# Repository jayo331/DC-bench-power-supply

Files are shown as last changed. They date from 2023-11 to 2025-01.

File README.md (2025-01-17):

# Multichannel linear bench power supply

Work in progress. At the start, i planned to add a switching pre-regulator and constant current control to an all-in-one linear regulator like lm350,lm317... The advantage of this solution is that since this regulator already comes with good line/load regulation i don't have to deal with extra stabilization. The problem is that those types of regulators also come with some big limits, some can not output voltages around zero, others can not handle the high current, and others are just too expensive for what they give, in general for all of the integrated solution voltage control (using DAC and MCU) is not as simple as i initially thought. Some regulators like 317 can be tweaked to output ~0V however the output is still limited to 1.5A in the case of the 317. I want to maintain the initial goals as much as possible (~0-25V, 5A per channel, simple) however commercial integrated linear regulators will not work without modifications. At this point, the only alternatives that come to mind are: 1) Tweak cheap regulators to reach voltages below 1.25V and boost the output current by adding an external pass transistor. 2) Build discretely a linear regulator that can handle these specs. For both solutions, extensive spice simulations are required to see which one performs better in dynamic load, transient, etc., and which one offers more performance at a price.

The regulators that i considered so far (without mod):

| | LM317 | LM350 | MIC29752 | LT3080 | LT3083 |
| --- | --- | --- | --- | --- | --- |
| 0V Capable | &cross; | &cross; | &cross; | &check; | &check; |
| 25V | &check; | &check; | &check; | &check; | &cross; |
| >/=5A | &cross; | &cross; | &check; | &cross; | &cross; |
| Active/In stock | &check; | &check; | &check; | &check; | &check; |
| Cheap? |Very inexpensive| Affordable | Very expensive| Affordable | Expensive |
| Easy to mod? | Easy | Easy | Difficult | Very easy | Easy |

After some simulations, i ended up considering the discrete linear topology, which shows good results even in dynamic load. The main advantages of this solution are price and flexibility, also a good side effect is that since no mysterious pre-made ic are involved it should be easy to tweak in case of future updates.

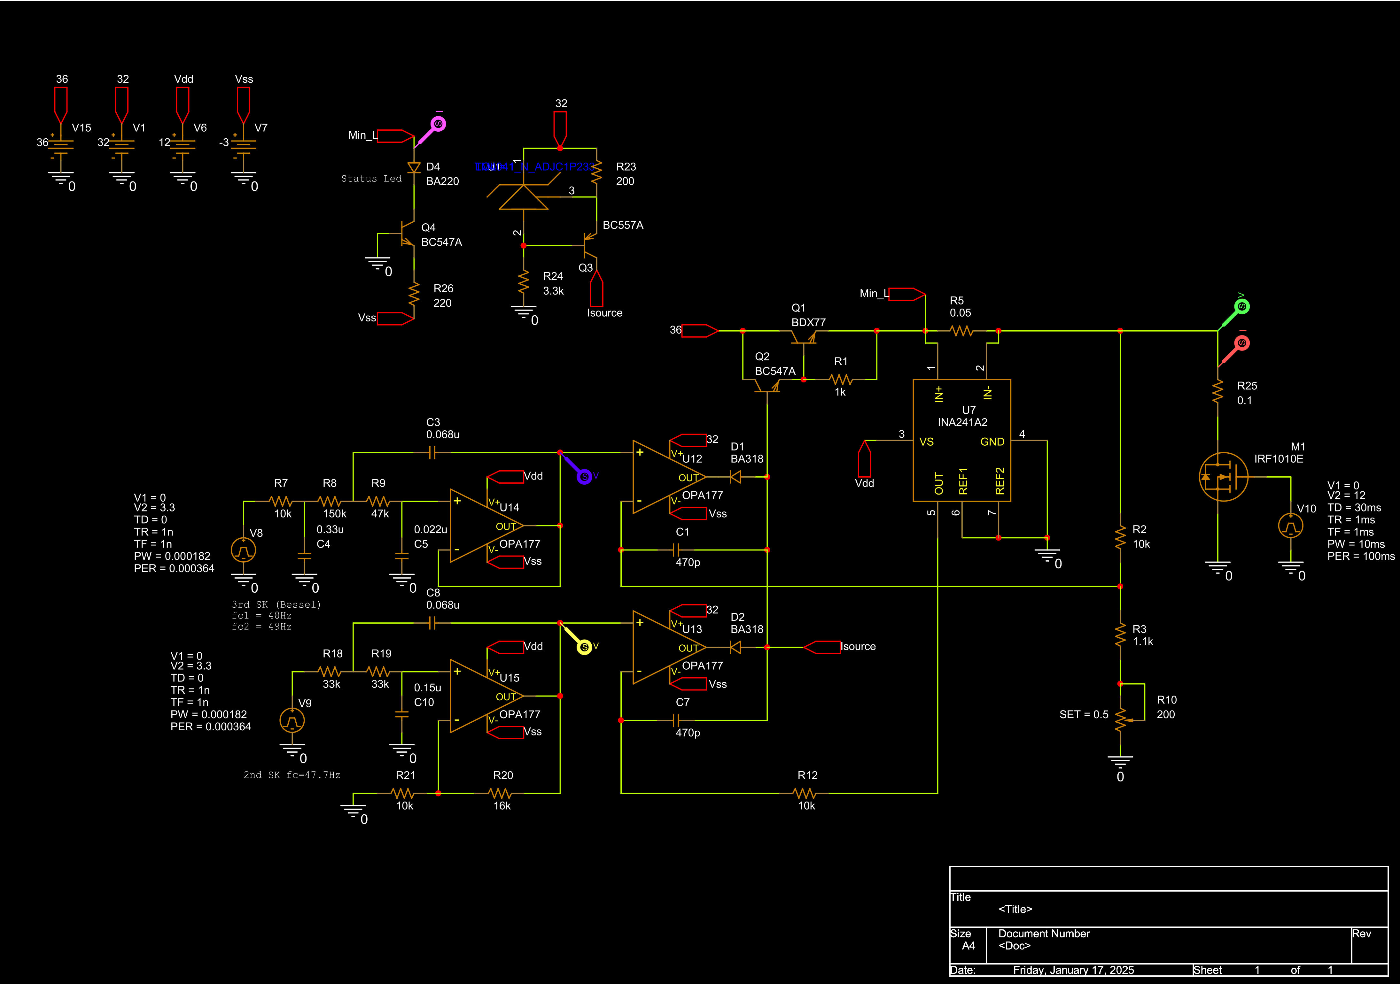
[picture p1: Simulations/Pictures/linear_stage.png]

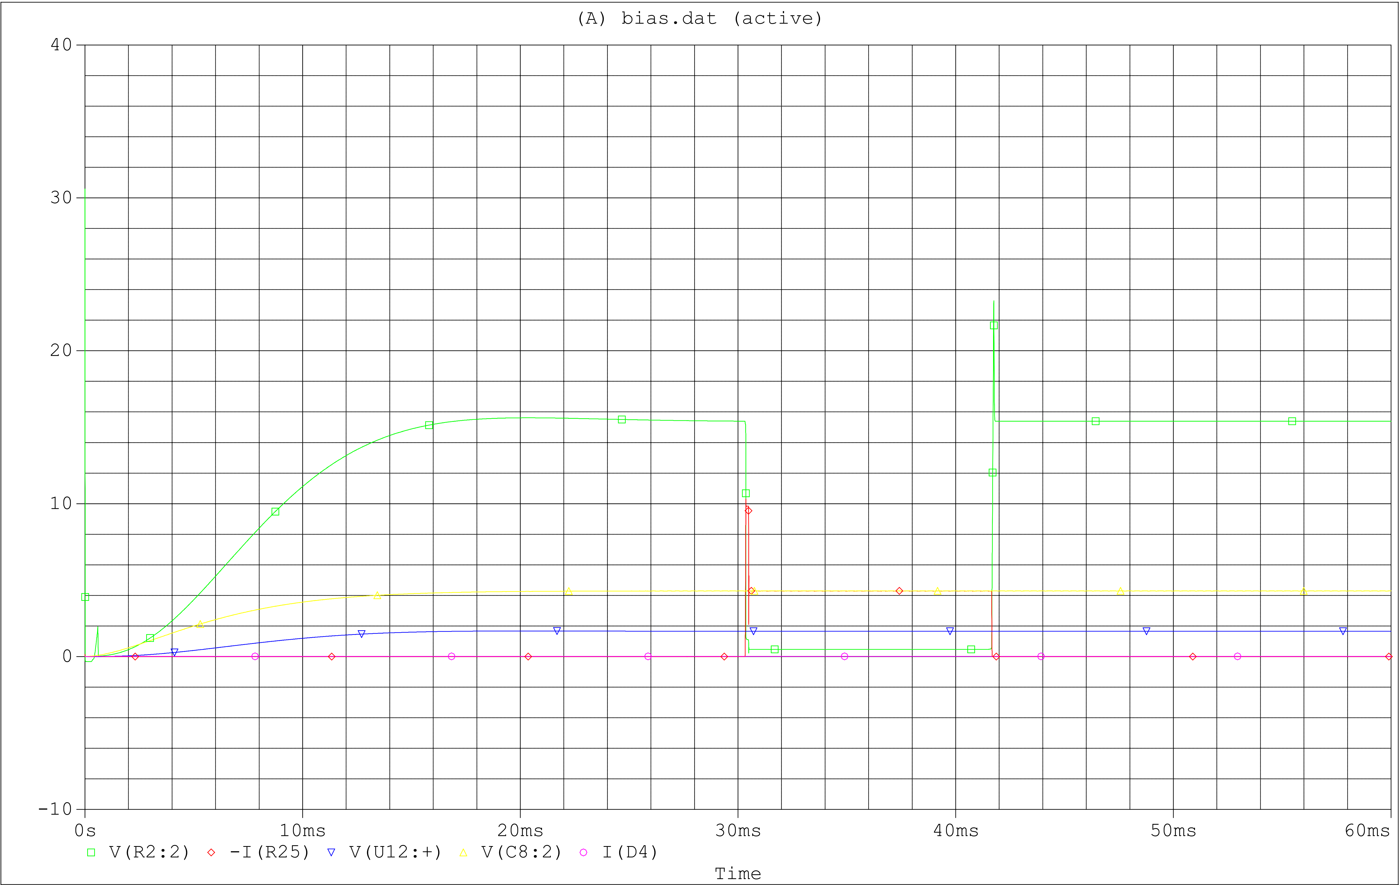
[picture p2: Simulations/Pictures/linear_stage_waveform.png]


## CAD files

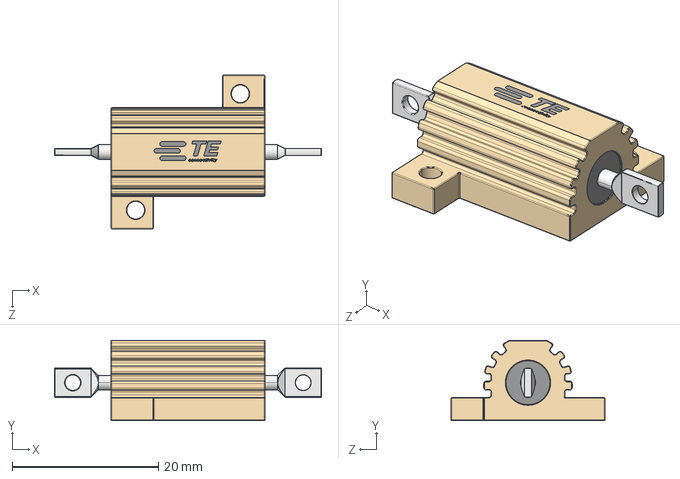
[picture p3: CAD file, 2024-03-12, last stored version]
multi_psu+tracking/Components/HSA10R10J/3D/HSA10R10J.stp
36.5 x 11.0 x 21.0 mm
HSA10R10J
TE Updated logo-LAPTOP-NQA1DCQ3

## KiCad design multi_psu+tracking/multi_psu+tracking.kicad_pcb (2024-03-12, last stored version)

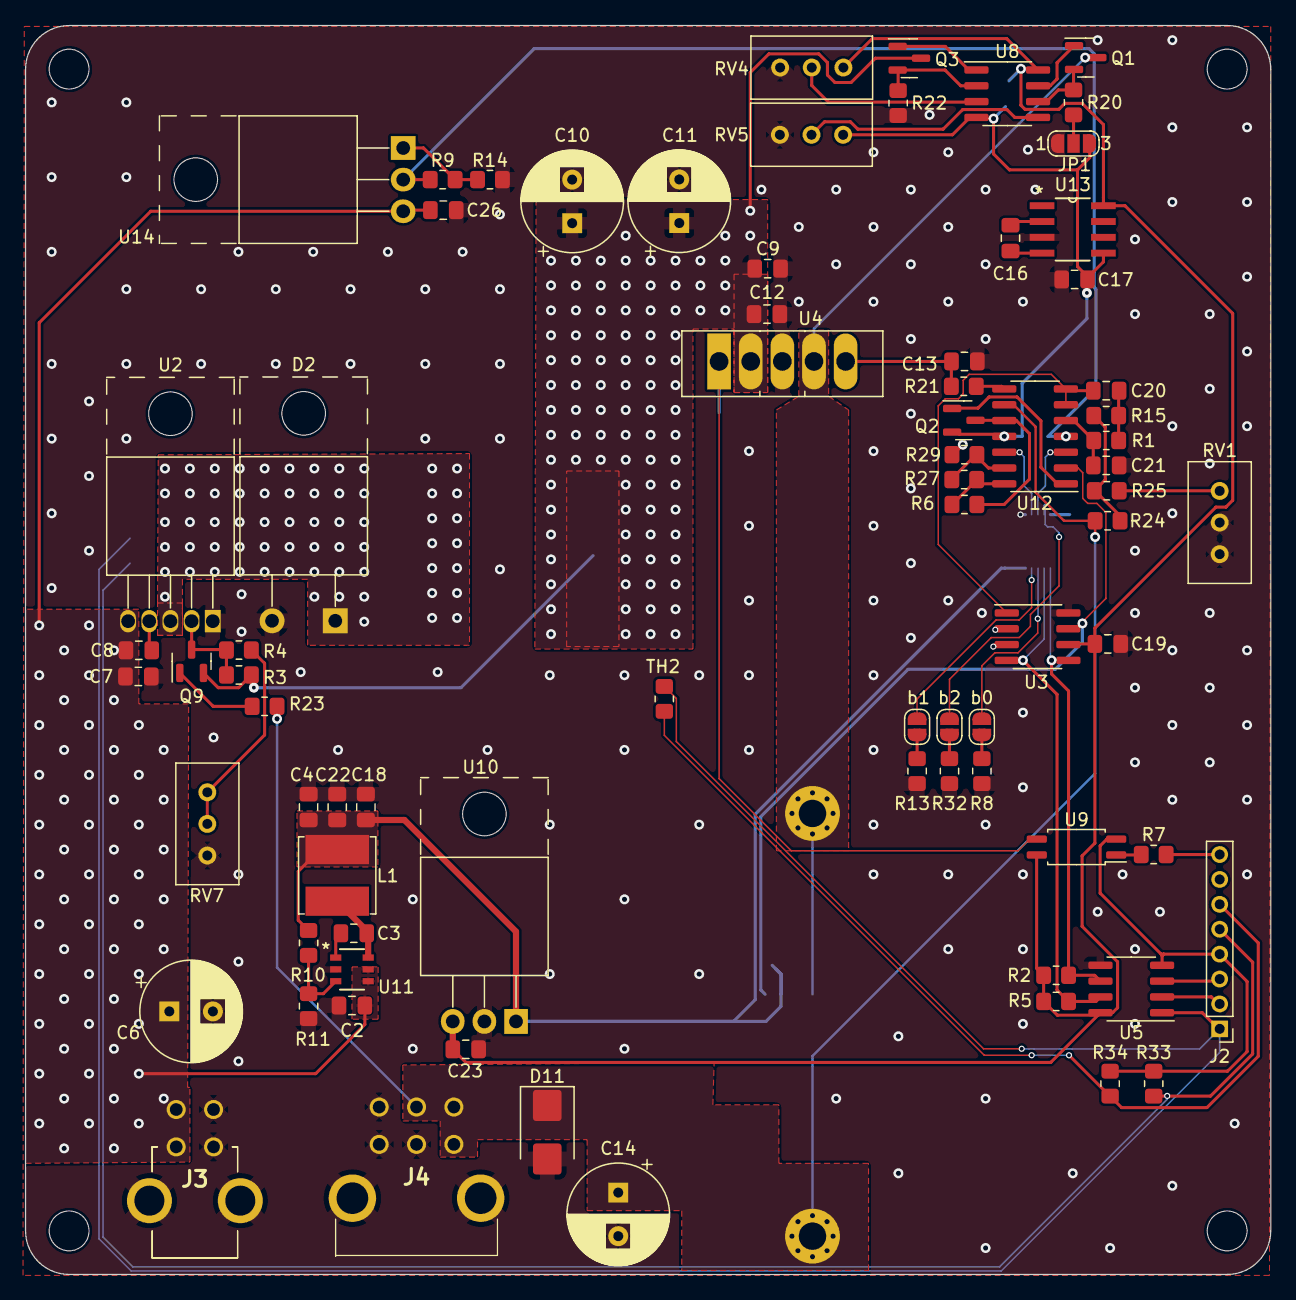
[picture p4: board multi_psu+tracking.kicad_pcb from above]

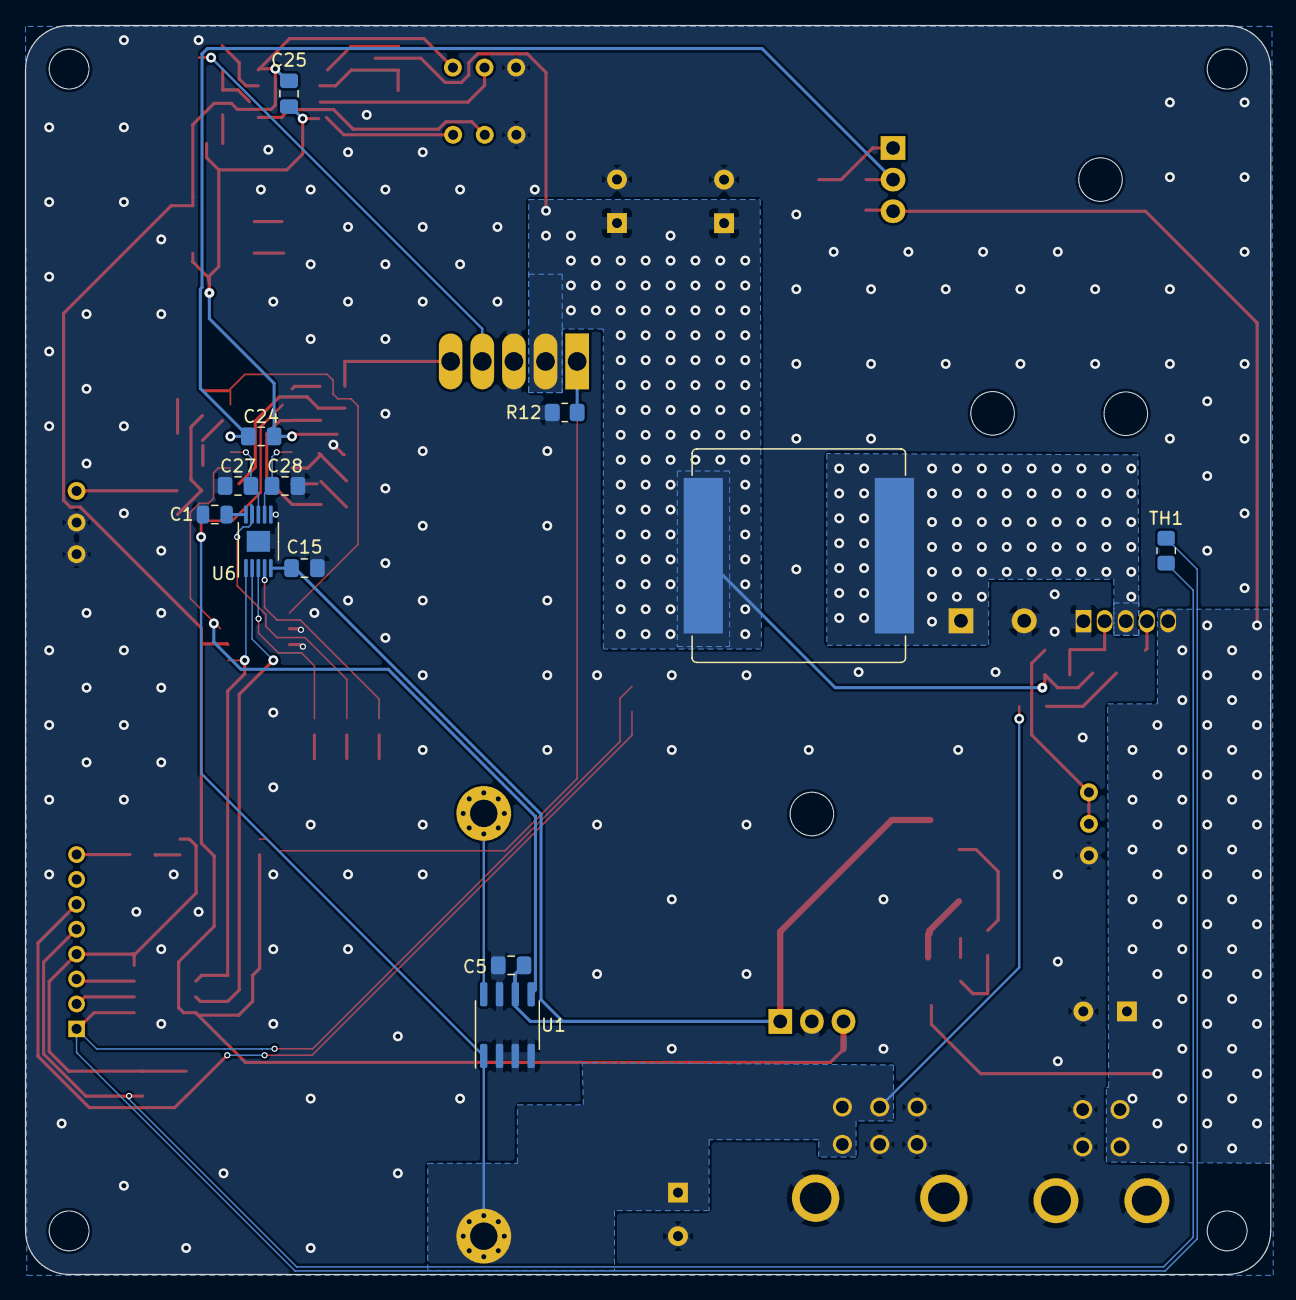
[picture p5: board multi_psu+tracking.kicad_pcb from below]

Board: 2 copper layers, 100.0 x 100.3 mm, 94 parts (12 on the bottom side), 59 nets.

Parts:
C1: 100n; C_0805_2012Metric
C2, C23, C26: 2.2u; C_0805_2012Metric_Pad1.18x1.45mm_HandSolder
C3, C5, C12, C15, C19, C24, C25, C27, C28: 100n; C_0805_2012Metric_Pad1.18x1.45mm_HandSolder
C4, C16, C17, C18, C22: 10u; C_0805_2012Metric_Pad1.18x1.45mm_HandSolder
C6: 470uF; CP_Radial_D8.0mm_P3.50mm
C7, C8, C9: 1uF; C_0805_2012Metric_Pad1.18x1.45mm_HandSolder
C10, C11: 1000uF; CP_Radial_D8.0mm_P3.50mm
C13: 1n; C_0805_2012Metric_Pad1.18x1.45mm_HandSolder
C14: 22u; CP_Radial_D8.0mm_P3.50mm
C20, C21: 1u; C_0805_2012Metric_Pad1.18x1.45mm_HandSolder
D2: BYV79-100; TO-220-2_Horizontal_TabUp
D11: SM6T27A; D_SMB
H1, H2, H3, H4: MountingHole; MountingHole_3.2mm_M3
H5, H6: MountingHole_Pad; MountingHole_2.2mm_M2_Pad_Via
J2: Conn_01x08_Pin; PinHeader_1x08_P2.00mm_Vertical
J3: 3-794677-4; 37946774
J4: 3-794677-6; 37946776
JP1: SolderJumper_3_Open; SolderJumper-3_P1.3mm_Open_RoundedPad1.0x1.5mm_NumberLabels
L1: 22u; L_Bourns_SRN6045TA
L2: 47uH; L_Bourns_SRP1770TA_16.9x16.9mm
Q1, Q2, Q3: 2N7002K; SOT-23
Q9: Si2319CDS; SOT-23
R1, R4, R8, R13, R15, R32: 4.7k; R_0805_2012Metric_Pad1.20x1.40mm_HandSolder
R2, R5: R; R_0805_2012Metric_Pad1.20x1.40mm_HandSolder
R3: 100k; R_0805_2012Metric_Pad1.20x1.40mm_HandSolder
R6: 2.2k; R_0805_2012Metric_Pad1.20x1.40mm_HandSolder
R7, R12: 1k; R_0805_2012Metric_Pad1.20x1.40mm_HandSolder
R9: 470; R_0805_2012Metric_Pad1.20x1.40mm_HandSolder
R10: 309k; R_0805_2012Metric_Pad1.20x1.40mm_HandSolder
R11: 22.1k; R_0805_2012Metric_Pad1.20x1.40mm_HandSolder
R14, R23, R29, R33, R34: 10k; R_0805_2012Metric_Pad1.20x1.40mm_HandSolder
R20, R22: 100; R_0805_2012Metric_Pad1.20x1.40mm_HandSolder
R21: 1; R_0805_2012Metric_Pad1.20x1.40mm_HandSolder
R24: 1M; R_0805_2012Metric_Pad1.20x1.40mm_HandSolder
R25: 200k; R_0805_2012Metric_Pad1.20x1.40mm_HandSolder
R27: 15k; R_0805_2012Metric_Pad1.20x1.40mm_HandSolder
RV1, RV4, RV5: 10k; Potentiometer_Bourns_3296W_Vertical
RV7: 500; Potentiometer_Bourns_3296W_Vertical
TH1, TH2: Thermistor_NTC; R_0805_2012Metric_Pad1.20x1.40mm_HandSolder
U1: INA241A1IDR; SOIC-8_3.9x4.9mm_P1.27mm
U2: XL4016; TO-220-5_Horizontal_TabUp
U3: MCP3422; SOIC-8_3.9x4.9mm_P1.27mm
U4: MIC29752WT; TO-247-5_Vertical
U5: ISO1640; SOIC-8_3.9x4.9mm_P1.27mm
U6: MSOP-10-1EP_3x3mm_P0.5mm_EP1.68x1.88mm
U8: LM358; SOIC-8_3.9x4.9mm_P1.27mm
U9: FODM217A; SOP-4_4.4x2.6mm_P1.27mm
U10: L7805; TO-220-3_Horizontal_TabUp
U11: AP64060QWU-7; IC6_AP64060QWU-7_DIO
U12: NCS21914; SOIC-14_3.9x8.7mm_P1.27mm
U13: TL7660CDR; D8
U14: LM317MBTG; TO-220-3_Horizontal_TabUp
b0, b1, b2: Jumper_2_Open; SolderJumper-2_P1.3mm_Open_RoundedPad1.0x1.5mm

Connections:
+5V: C19.2, C23.1, C25.1, R2.1, R5.2, RV4.1, U3.6 (Vss), U5.8 (VCC2), U8.8 (V+), U9.4, U10.3 (OUT), U13.8 (VCC)
+5VA: J2.1, TH1.1, TH2.1, U5.1 (VCC1)
+12V: C4.1, C5.2, C15.2, C18.1, C22.1, L1.2, R10.1, U1.6 (V+), U6.5 (VCC), U10.1 (IN)
+28V: C24.1, R9.1, U12.4 (V+), U14.2 (VO)
+36V: C2.1, C6.1, C7.1, C8.1, C26.1, J3.1, J3.2, U2.5 (VIN), U11.4 (EN), U11.5 (VIN), U14.3 (VI)
-5V: C17.1, C24.2, C25.2, JP1.3 (B), Q2.2 (S), RV5.3, U8.4 (V-), U12.11 (V-), U13.5 (VOUT)
ENABLE: R12.2, U4.1 (EN), U9.3
GND: C1.2, C2.2, C4.2, C5.1, C6.2, C7.2, C9.2, C10.2, C11.2, C12.2, C13.1, C14.2, C15.1, C17.2, C18.2, C19.1, C21.1, C22.2, C23.2, C26.2, C27.2, C28.2, D2.2 (A), D11.2 (A2), J3.3, J3.4, J3.MH1, J3.MH2, J4.1, J4.2, J4.3, J4.MH1, J4.MH2, JP1.1 (A), R8.2, R11.2, R12.1, R13.2, R14.2, R22.2, R29.1, R32.2, RV1.2, RV1.3, RV4.3, RV5.1, RV7.3, U1.2 (GND), U1.3 (REF2), U1.4 (GND), U1.7 (REF1), U2.1 (GND), U3.2 (CH1-), U3.3 (Vdd), U3.8 (CH2-), U4.3 (GND), U5.5 (GND2), U6.6 (GND), U6.11, U10.2 (GND), U11.2 (GND), U13.3 (GND)
GNDS: J2.4, R33.1, R34.1, U5.4 (GND1), U9.2
I_Sense: U1.5, U3.7 (CH2+), U12.2 (-)
I_ctrl: C27.1, U6.8 (VOUT2), U12.3 (+)
LIN_temp: J2.6, R34.2, TH2.2
unnamed: C20.1, R1.1, R15.2
unnamed: D2.1 (K), L2.1, U2.3 (SW)
unnamed: J2.2, U5.2 (SDA1)
unnamed: J2.3, U5.3 (SCL1)
unnamed: J2.8, R7.1
unnamed: JP1.2 (C), R20.2
unnamed: U6.9 (A2), b2.1 (A)
unnamed: R32.1, b2.2 (B)
unnamed: U6.3 (A0), b0.1 (A)
unnamed: R8.1, b0.2 (B)
unnamed: U6.4 (A1), b1.1 (A)
unnamed: R13.1, b1.2 (B)
unnamed: Q1.1 (G), U8.7
unnamed: Q1.2 (S), R20.1, U8.6 (-)
unnamed: Q2.3 (D), R6.2, U12.10 (+)
unnamed: Q2.1 (G), U12.1
unnamed: Q3.1 (G), U8.1
unnamed: Q3.2 (S), R22.1, U8.2 (-)
unnamed: Q9.3 (D), R3.2, R4.1, U2.2 (FB)
unnamed: Q9.1 (G), R23.1
unnamed: R4.2, RV7.1, RV7.2
unnamed: R7.2, U9.1
unnamed: R15.1, R24.2, R25.1
unnamed: R21.2, U12.8
unnamed: R25.2, RV1.1
unnamed: R6.1, R27.2, U12.14
unnamed: C8.2, U2.4 (VC)
unnamed: C13.2, R21.1, U4.5 (ADJ)
unnamed: C1.1, U6.10 (V5V)
unnamed: RV4.2, U8.3 (+)
unnamed: RV5.2, U8.5 (+)
unnamed: C3.2, U11.1 (BST)
unnamed: R10.2, R11.1, U11.3 (FB)
unnamed: C3.1, L1.1, U11.6 (SW)
unnamed: C21.2, R1.2, U12.5 (+)
unnamed: R27.1, R29.2, U12.13 (-)
unnamed: C16.1, U13.2 (CAP+)
unnamed: C16.2, U13.4 (CAP-)
unnamed: R9.2, R14.1, U14.1 (ADJ)
PREREG_temp: J2.5, R33.2, TH1.2
PRE_OUT: C9.1, C10.1, C11.1, C12.1, L2.2, Q3.3 (D), Q9.2 (S), R3.1, U4.2 (VIN)
S+: H5.1, Q1.3 (D), U1.8 (+), U4.4 (VOUT)
S-: C14.1, D11.1 (A1), H6.1, J4.4, J4.5, J4.6, R23.2, R24.1, U1.1 (-), U12.9 (-)
SCL: R2.2, U3.5 (SCL), U5.6 (SCL2), U6.1 (SCK)
SDA: R5.1, U3.4 (SDA), U5.7 (SDA2), U6.2 (SDA)
V_Sense: C20.2, U3.1 (CH1+), U12.6 (-), U12.7
V_ctrl: C28.1, U6.7 (VOUT1), U12.12 (+)

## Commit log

2024-01-01 Minor design update
    [multi_psu+tracking.kicad_pcb, multi_psu+tracking.kicad_sch]
2024-02-18 Architecture update
    [multi_psu+tracking.kicad_pcb, multi_psu+tracking.kicad_sch]
2025-01-17 Add linear post regulator images
